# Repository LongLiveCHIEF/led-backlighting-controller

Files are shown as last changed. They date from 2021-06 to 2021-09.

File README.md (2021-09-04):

# LED Backlighting Controller

This project is designed to control a strip of ws2812 LED's that serve to backlight wall-hung art.

At the moment, in it's earliest viable release form, it has one momentary push button that is used
to cycle through the available solid color lighting choices.

Future updates for this project will support a potentiometer for dimming, and various animation modes.

## Build and Flash

```
cargo build --release
cargo hf2 --release
```

## Video Demo

YouTube Demo (https://youtu.be/AdlcyJdxIKM)

## Electrical Schematic

schematic

## Power Usage
Power values below from ws2812 strip of 20 led's

| Color | mA @ max brightness | mA @ 50% brightness | mA @ 10% brightness |
| ----- | --- | --- | --- |
| WHITE | 14.30 | 7.26 | 2.05 |
| RED | 5.28 | 3.13 | 1.74 |
| GREEN | 3.11 | 2.25 | 1.65 |
| BLUE | 5.26 | 3.15 | 1.73 |

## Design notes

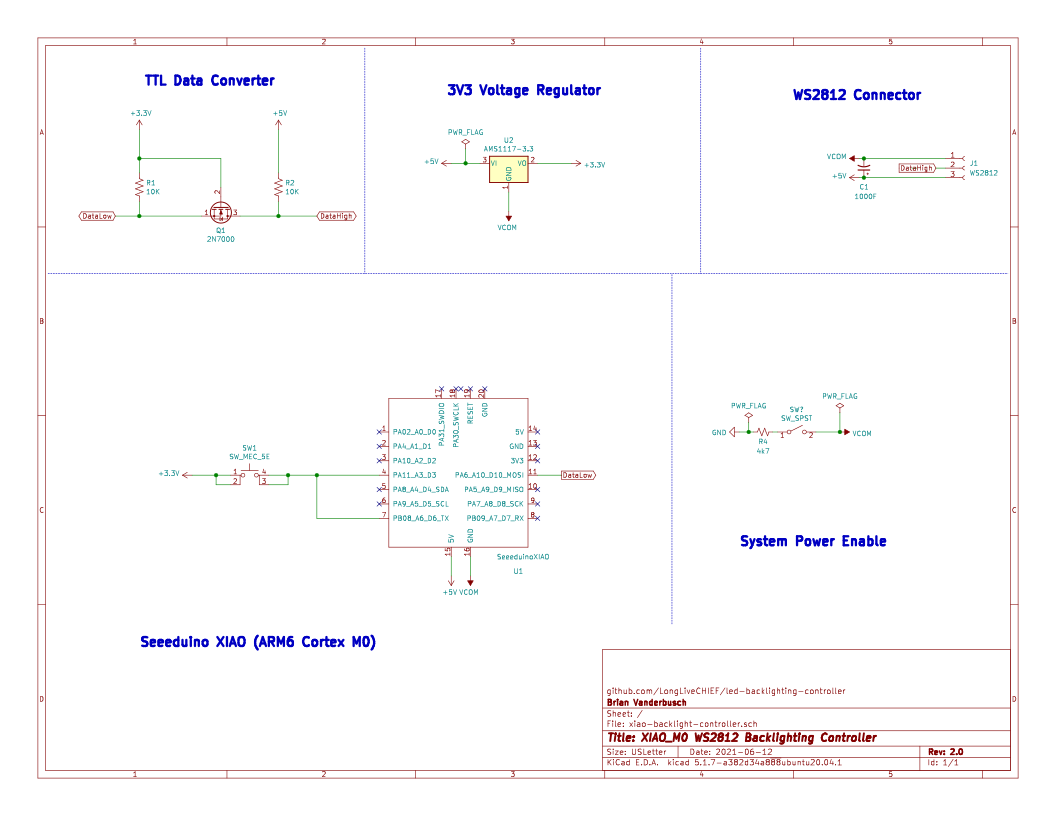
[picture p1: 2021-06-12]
schematic.png

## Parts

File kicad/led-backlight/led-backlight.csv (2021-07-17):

Comment | Designator | Footprint | LCSC Part #
22uF Polarized capacitor, small US symbol | C1,C5 | CP_EIA-3528-12_Kemet-T | C8020
10uF Unpolarized capacitor, small symbol | C2,C6 | C_0805_2012Metric | C15850
330uF Polarized capacitor, small US symbol | C3,C4 | CP_EIA-3528-12_Kemet-T | C178370
BSS138 50V Vds, 0.22A Id, N-Channel MOSFET, SOT-23 | Q1 | SOT-23 | C52895
10k Resistor, small US symbol | R1,R2 | R_0805_2012Metric | C17414
AMS1117-3.3 1A Low Dropout regulator, positive, 3.3V fixed output, SOT-223 | U1,U3 | SOT-223-3_TabPin2 | C6186

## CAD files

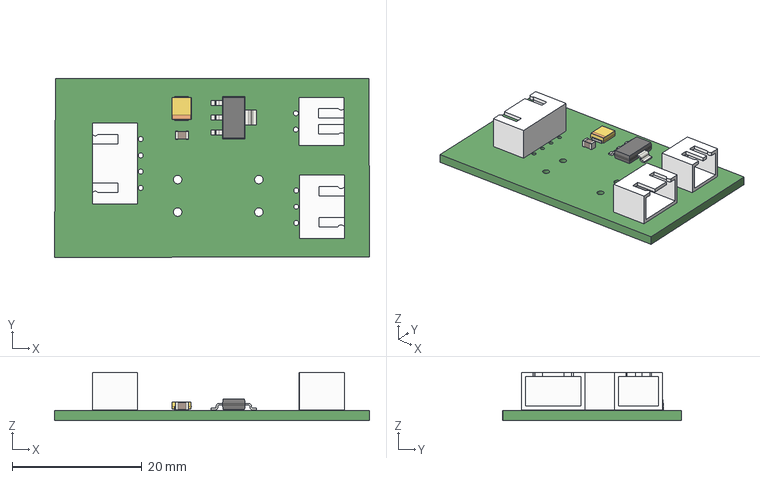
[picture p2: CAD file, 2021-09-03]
kicad/led-backlight/led-backlight-controls/led-backlight-controls.step
48.5 x 27.5 x 7.45 mm

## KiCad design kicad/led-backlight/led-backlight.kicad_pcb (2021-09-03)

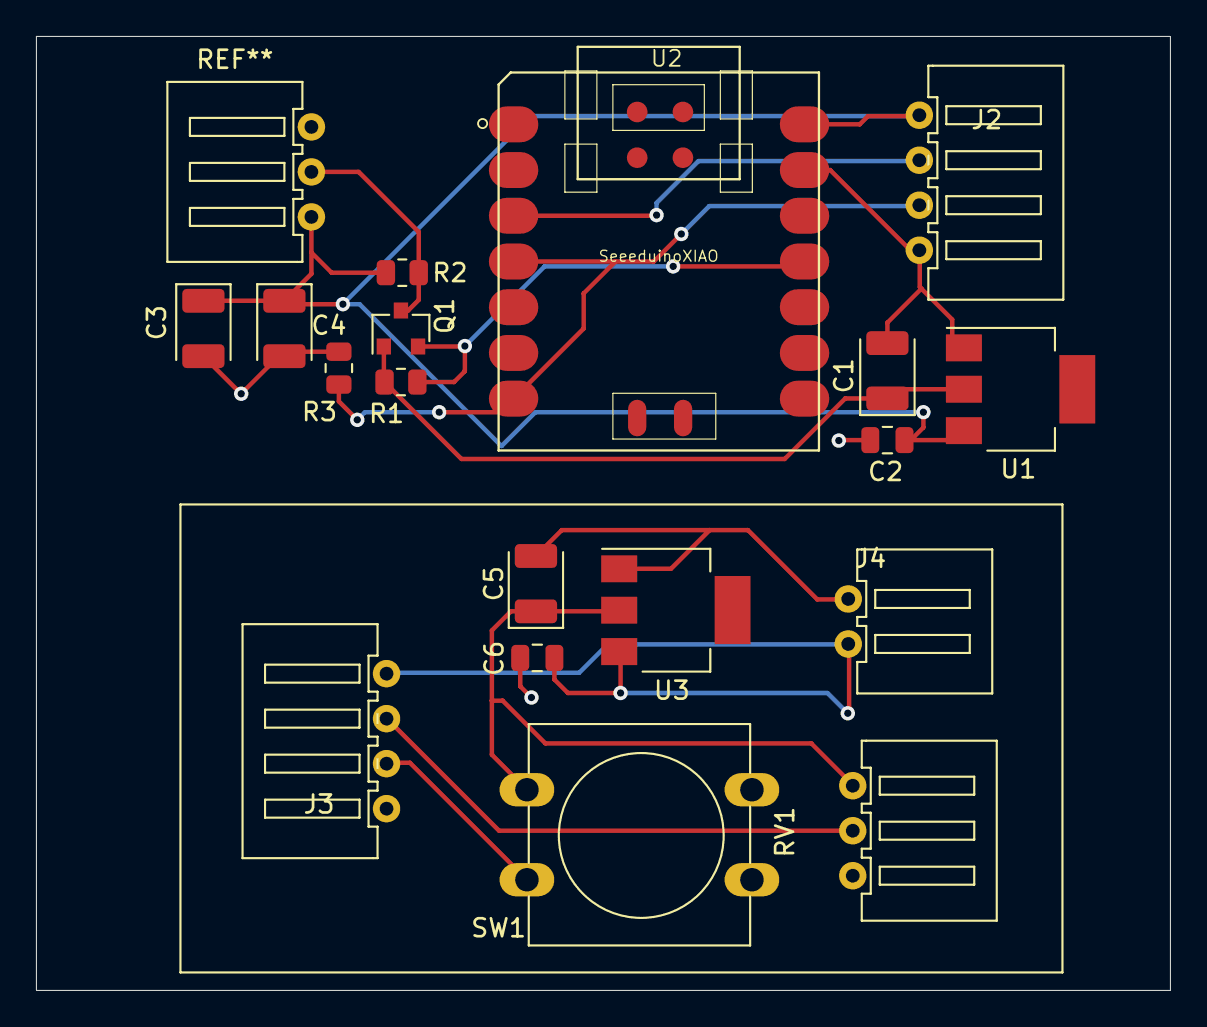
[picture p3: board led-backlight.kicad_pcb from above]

Board: 2 copper layers, 63.0 x 53.0 mm, 18 parts (0 on the bottom side), 7 nets.

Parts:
C1, C5: 22uF; CP_EIA-3528-12_Kemet-T
C2, C6: 10uF; C_0805_2012Metric
C3, C4: 330uF; CP_EIA-3528-12_Kemet-T
J2, J3: jst_xh_conn_1x04_horizontal
J4: jst_xh_conn_1x02_horizontal
Q1: BSS138; SOT-23
R1, R2: 10k; R_0805_2012Metric
R3: R_0805_2012Metric
RV1: R_POT_US; jst_xh_conn_1x03_horizontal
SW1: SW_MEC_5E; SW_PUSH-12mm
U1, U3: AMS1117-3.3; SOT-223-3_TabPin2
U2: SeeeduinoXIAO; Seeeduino XIAO-MOUDLE14P-2.54-21X17.8MM

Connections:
+5V: C2.2, C3.1, C4.1, C6.2, J2.1, J3.1, R2.1, U1.3, U2.14, U3.3
/mcu_board/+3V: C1.1, Q1.1, R1.1, U1.2
/mcu_board/DataHigh: Q1.3, R2.2
/mcu_board/DataLow: Q1.2, R1.2, U2.11
/mcu_board/mode_btn: C5.1, J2.3, J3.2, R3.2, RV1.3, SW1.1, SW1.2, U2.4, U2.7, U3.2
/mcu_board/mode_ref: J2.2, J3.3, RV1.2, U2.3
GND: C1.2, C2.1, C3.2, C4.2, C5.2, C6.1, J3.4, J4.2, R3.1, RV1.1, U1.1, U2.13, U3.1

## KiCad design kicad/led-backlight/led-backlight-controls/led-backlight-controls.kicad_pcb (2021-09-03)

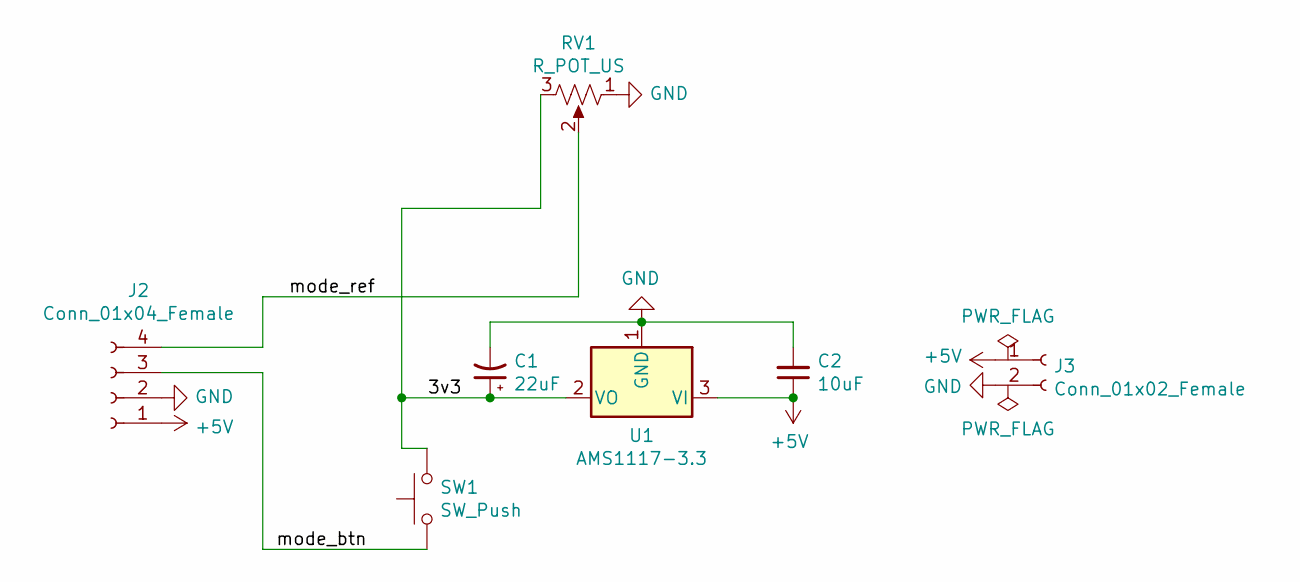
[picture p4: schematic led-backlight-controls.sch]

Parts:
C1: 22uF; CP_EIA-3528-12_Kemet-T
C2: 10uF; C_0805_2012Metric
J2: Conn_01x04_Female; jst_xh_conn_1x04_horizontal
J3: Conn_01x02_Female; jst_xh_conn_1x02_horizontal
RV1: R_POT_US; jst_xh_conn_1x03_horizontal
SW1: SW_Push; SW_PUSH-12mm
U1: AMS1117-3.3; SOT-223-3_TabPin2

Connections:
+5V: C2.1, J2.1, J3.1, U1.3 (VI)
/3v3: C1.1, RV1.3, SW1.2, U1.2 (VO)
/mode_btn: J2.3, SW1.1
/mode_ref: J2.4, RV1.2
GND: C1.2, C2.2, J2.2, J3.2, RV1.1, U1.1 (GND)

Board: 2 copper layers, 7 parts (0 on the bottom side), 5 nets, no tracks yet.

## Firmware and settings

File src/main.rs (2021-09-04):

#![no_main]
#![no_std]
#![allow(non_snake_case)]

extern crate xiao_m0 as hal;
use panic_rtt_target as _;

#[rtic::app(device = hal::pac, peripherals = true, dispatchers = [TCC0])]
mod app {
    use core::convert::TryInto;
    use atsamd_hal::adc::Adc;
    use hal::clock::{ClockGenId, ClockSource, GenericClockController};
    use hal::rtc::{Count32Mode, Rtc};
    use hal::spi_master;
    use hal::gpio::{ Input, Floating, Pb8, Pa5, Pa6, Pa7, Pa10, Pa11, PfD, PfA, PfB};
    use hal::eic::{pin::{Sense, ExtInt8}, EIC};
    use hal::sercom::{Sercom0Pad1, Sercom0Pad2, Sercom0Pad3};
    use hal::prelude::*;
    use heapless::Vec;
    use rtic::time::{duration::Milliseconds, Instant};
    use rtt_target::{rprintln, rtt_init_print};
    use ws2812_spi::Ws2812 as ws2812;
    use smart_leds::{brightness, RGB8, SmartLedsWrite, colors::{WHITE, RED, GREEN, BLUE, YELLOW}};


    #[monotonic(binds = RTC, default = true)]
    type RtcMonotonic = Rtc<Count32Mode>;

    #[shared]
    struct Shared {
        ledString: ws2812<hal::sercom::SPIMaster0<Sercom0Pad1<Pa5<PfD>>, Sercom0Pad2<Pa6<PfD>>, Sercom0Pad3<Pa7<PfD>>>>,
        button: ExtInt8<Pb8<PfA>>,
        modeDetectPin: Pa11<Input<Floating>>,
        colors: core::iter::Cycle<<heapless::Vec<[smart_leds::RGB<u8>; 20], 5_usize> as IntoIterator>::IntoIter>,
        adc: atsamd_hal::adc::Adc<hal::pac::ADC>,
        controlKnob: Pa10<PfB>,
    }

    #[local]
    struct Local {}

    #[init]
    fn init(cx: init::Context) -> (Shared, Local, init::Monotonics) {
        const NUM_LEDS: usize = 20;
        let mut peripherals = cx.device;
        let mut pins = hal::Pins::new(peripherals.PORT);
        let mut clocks = GenericClockController::with_external_32kosc(
            peripherals.GCLK,
            &mut peripherals.PM,
            &mut peripherals.SYSCTRL,
            &mut peripherals.NVMCTRL,
        );

        // initialize monotonic
        let rtc_clock_src = clocks
            .configure_gclk_divider_and_source(ClockGenId::GCLK2, 1, ClockSource::XOSC32K, false)
            .unwrap();
        clocks.configure_standby(ClockGenId::GCLK2, true);
        let rtc_clock = clocks.rtc(&rtc_clock_src).unwrap();
        let rtc = Rtc::count32_mode(peripherals.RTC, rtc_clock.freq(), &mut peripherals.PM);

        // setup led control SPI
        let spi = spi_master(
            &mut clocks,
            2600.khz(),
            peripherals.SERCOM0,
            &mut peripherals.PM,
            pins.a8,
            pins.a10,
            pins.a9,
            &mut pins.port
        );
        let ledString = ws2812::new(spi);

        let gclk0 = clocks.gclk0();

        // initialize color control button
        let eic_clock = clocks.eic(&gclk0).unwrap();
        let mut eic = EIC::init(&mut peripherals.PM, eic_clock, peripherals.EIC);
        let mut button = pins.a6.into_ei(&mut pins.port);
        button.sense(&mut eic, Sense::BOTH);
        button.enable_interrupt(&mut eic);
        let modeDetectPin = pins.a3.into_floating_input(&mut pins.port);

        // initialize brightness control knob
        let adc = Adc::adc(peripherals.ADC, &mut peripherals.PM, &mut clocks);
        let controlKnob = pins.a2.into_function_b(&mut pins.port);

        let mut colorCollection: Vec<[smart_leds::RGB8; NUM_LEDS], 5> = Vec::new();
        let red: [RGB8; NUM_LEDS] = [RED; NUM_LEDS];
        let yellow: [RGB8; NUM_LEDS] = [YELLOW; NUM_LEDS];
        let green: [RGB8; NUM_LEDS] = [GREEN; NUM_LEDS];
        let blue: [RGB8; NUM_LEDS] = [BLUE; NUM_LEDS];
        let white: [RGB8; NUM_LEDS] = [WHITE; NUM_LEDS];
        colorCollection.push(red).unwrap();
        colorCollection.push(yellow).unwrap();
        colorCollection.push(green).unwrap();
        colorCollection.push(blue).unwrap();
        colorCollection.push(white).unwrap();
        let colors = colorCollection.into_iter().cycle();
        writeLeds::spawn().unwrap();
        rtt_init_print!();
        rprintln!("Initialization complete!");

        ( Shared { ledString, button, modeDetectPin, colors, adc, controlKnob }, Local {}, init::Monotonics(rtc)) }

      // Optional idle task, if left out idle will be a WFI.
    #[idle]
    fn idle(_cx: idle::Context) -> ! {
        rprintln!("Hello from idle!");

        loop {
            // Do some work or WFI.
            continue;
        }
    }

    #[task(binds = EIC, shared=[button], priority = 2)]
    fn onButtonInterrupt(mut cx: onButtonInterrupt::Context) {
        cx.shared.button.lock(|button| button.clear_interrupt());
        debounce::spawn_after(Milliseconds(30_u32)).ok();
    }

    #[task(shared = [modeDetectPin], local = [
        hold: Option<hold::SpawnHandle> = None,
        pressed_at: Option<Instant<RtcMonotonic>> = None
    ])]
    fn debounce(mut cx: debounce::Context){
        let HOLD = cx.local.hold;
        let PRESSED_AT = cx.local.pressed_at;
        if let Some(handle) = HOLD.take() {
            handle.cancel().ok();
        }

        if cx.shared.modeDetectPin.lock(|b| b.is_high().unwrap()) {
            PRESSED_AT.replace(monotonics::RtcMonotonic::now());
            *HOLD = hold::spawn_after(Milliseconds(1000u32)).ok();
        } else {
            if PRESSED_AT
                .take()
                .and_then(|i| monotonics::RtcMonotonic::now().checked_duration_since(&i))
                .and_then(|d| d.try_into().ok())
                .map(|t: Milliseconds<u32>| t < Milliseconds(1000_u32))
                .unwrap_or(false) {
                    rprintln!("changing mode value");
                    writeLeds::spawn().unwrap();
                }
        }
    }

    #[task(shared = [modeDetectPin])]
    fn hold(mut cx: hold::Context){
        if cx.shared.modeDetectPin.lock(|b| b.is_high().unwrap()) {
            rprintln!("selecting mode");
        }
    }

    #[task(shared = [ledString, colors, adc, controlKnob])]
    fn writeLeds(cx: writeLeds::Context){
        let _ledString = cx.shared.ledString;
        let _colors = cx.shared.colors;
        let _adc = cx.shared.adc;
        let _controlKnob = cx.shared.controlKnob;

        (_ledString, _colors, _adc, _controlKnob).lock(|_ledString, _colors, _adc, _controlKnob| {
            let data: u16 = _adc.read(_controlKnob).unwrap();
            let data: u8 = ( data >> 4) as u8;
            rprintln!("brightness value: {}", data);
            let newColor: Option<[RGB8; 20]> = _colors.next();
            if let Some(i) = newColor {
                _ledString.write(brightness(i.iter().cloned(), data)).unwrap();
            }
        });
    }
}

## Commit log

2021-04-09 setup a blinky pin
2021-04-23 update probe speed
2021-04-24 for some reason using atsamd21e17 works on a g18
    [unbrick-xiao.cfg]
2021-04-24 update default probe
2021-05-03 ensure optimizations so timing of spi
2021-05-04 prevent blindness during development
    [main.rs]
2021-05-06 patch ws2812-spi-rs
2021-05-07 use more appropriate interrupt vector
2021-05-07 example buttons
2021-05-07 setup button as interrupt
2021-05-08 working hardware interrupt button
2021-05-11 configure pin 4 as mode detection pin
2021-05-12 create input-pin example
2021-05-13 tweak spi timing
2021-05-23 make one led iterable
2021-06-05 write to all leds on color change
2021-06-05 add schematic
2021-06-06 add power documentation
2021-06-12 added new schematic
2021-06-13 log raw adc input
2021-06-13 fix controlKnob pin initialization
    [main.rs]
2021-07-17 add ignores for kicad source control
2021-07-17 schematics complete
    [led-backlight.kicad_pcb, led-backlight.sch, mcu_board.sch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]
2021-07-17 add board stackup
    [led-backlight.kicad_pcb, mcu_board.sch, power_and_control_board.sch]
2021-07-17 update board track routing
    [led-backlight.kicad_pcb]
2021-07-17 finish kicad project v1
    [led-backlight-B_Cu.gbl, led-backlight-B_Mask.gbs, led-backlight-B_Paste.gbp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]
2021-07-17 add kicad project
    [led-backlight.csv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]
2021-07-17 add pulldown resistor to eic pin
    [led-backlight.kicad_pcb, mcu_board.sch]
2021-09-03 idk can't remember
    [led-backlight-controls.kicad_pcb, led-backlight-controls.sch, led-backlight-controls.step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]
2021-09-04 broken attempt at upgradeing rtic
    [main.rs]
